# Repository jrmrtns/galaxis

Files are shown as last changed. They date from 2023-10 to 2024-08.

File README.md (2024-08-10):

# Galaxis

A tribute to Galaxis, an electronic game from Ravensburger, I loved to play as child.
<br/>This version of the game runs on a ESP32-C3 or ESP32-S3 and makes use of Bluetooth LE to connect up to four players.

The game is a kind of deductive boardgame like Mastermind for one to two players. The goal of the game is to discover
missing space ships, lost in space. These ships can be found if you enter coordinates into the board computer. Then the
computer answers with the number of ships which can be seen in horizontally, vertically or diagonal in a direct
line.<br/>
Who will find the missing spaceships first?

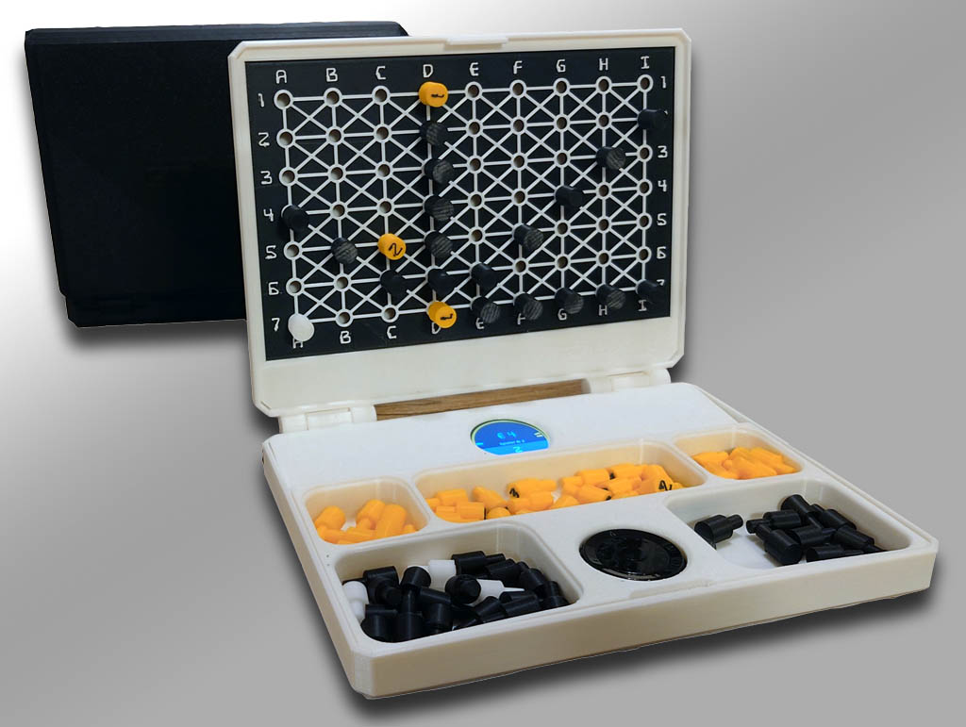
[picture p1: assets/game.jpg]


## Rules

Alarm at headquarters. Four spaceships are missing. By sending out radio signals in the different
directions, how many of the spaceships are seen from a certain point is reported back.

* Player A starts a new game by turning the dial until "New" appears on the display and confirming by pressing the
  middle button to confirm
* Up to three additional players can join a game by pressing "Join".
* A yellow ring on the screen indicates the active player
* The player sets a coordinate and presses the middle button.
* The search begins, a radio beam is emitted. Either a number appears on the screen, or a star if one of the ships has
  been found.
    * The number indicates how many of the spaceships can be seen in a horizontal, vertical or diagonal direction. The
      player plugs one of the yellow number pins into the coordinate on the coordinate system.
    * However, it should be noted that spaceships can lie in the radio shadow. This means that spaceships that
      in a direct line behind another spaceship are obscured by the first one and therefore cannot be seen.
      be seen.
      Example: Assume there are two spaceships at points C1 and C4. Then the radio beam from coordinate
      C7 only sees one spaceship (C4). The spaceship C1 is obscured. From position C3, however, two spaceships can be
      seen.
    * The black pins can be used to turn off coordinates where no more spaceships can be anymore.
    * If a spaceship has been found, this is indicated by '*' and the player has another turn
    * If there is a number, it is the next player's turn
    * While the game goes further, the players draw their conclusions from the coordinates entered and continue searching at the intersections.
* The first player to find all four spaceships wins the game.
* Press the middle button to start a new game.

Translated with www.DeepL.com/Translator (free version)

[The original rules from 1980 (in german language)](https://www.ravensburger.de/spielanleitungen/ecm/Spielanleitungen/Galaxis_Electronic.pdf)

## Deployment
If you prefer to use a precompiled version, just connect a suitable device to the USB port on your computer and visit [https://jrmrtns.github.io/galaxis/](https://jrmrtns.github.io/galaxis/)
in Chrome or Edge browser and follow instructions on the page.

## Build

The build-process requires an installation
of [PlatformIO Core CLI](https://docs.platformio.org/en/stable/core/index.html#piocore), or your favorite IDE with a
PlatformIO extension.

In case of PlatformIO Core CLI, please follow these instructions:

* `git clone https://github.com/jrmrtns/galaxis.git`
* `cd ./galaxis/Galaxis`
* Connect a Seeed XIAO ESP323 with a USB-C cable to your computer
* `pio run -e seeed_xiao_esp32c3 --target upload`

## Schematic

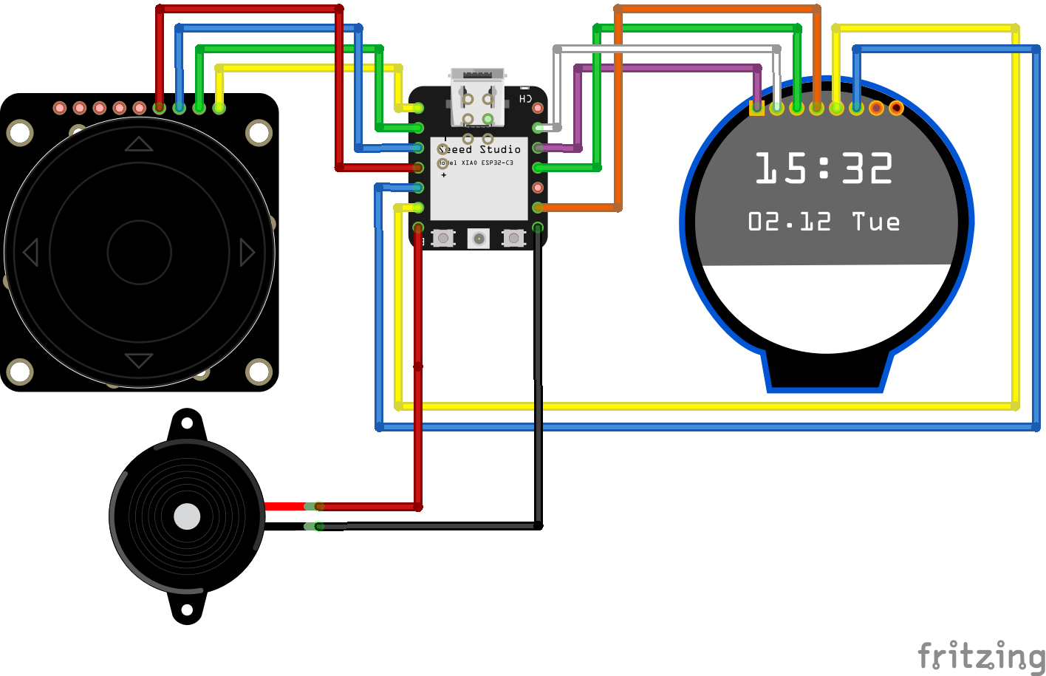
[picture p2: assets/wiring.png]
wiring diagram


## BOM

* [Display Waveshare 1.28 Round](https://www.berrybase.de/en/1.28-240x240-rundes-lcd-display-modul-65k-rgb-spi-interface?c=2384
  )

* [Seeed XIAO ESP32-C3](https://www.berrybase.de/en/seeed-xiao-esp32c3-winziges-mcu-board-mit-wlan-und-ble
  ) or [Seeed XIAO ESP32-S3](https://www.seeedstudio.com/XIAO-ESP32S3-p-5627.html)

* [Adafruit ANO Rotary Encoder](https://www.berrybase.de/en/adafruit-ano-scrollrad-drehgeber)

* [PCB for Adafruit ANO Rotary Encoder](https://www.berrybase.de/en/adafruit-breakout-pcb-fuer-ano-scrollrad-drehgeber)

* [Speaker (optional)](https://www.amazon.de/dp/B00X77TY96)

## 3D Files

Even if there is a single player version, I recommend to print the deck minimum twice. The hardware can connect up to four decks. 
To assemble one deck, you need to print all the following parts:

* 1 x [Bottom of the case](./3d/Boden.stl)
* 1 x [Lid of the case](./3d/Deckel.stl)
* 1 x [Inlay for the case](./3d/Inlay.stl)
* 1 x [Plate for the display](./3d/Display.stl)
* 1 x [Plate for the pins](./3d/Platte.stl)
* 50 x [Black Pins](./3d/BlackPin.stl)
* 5 x [Pin 0](./3d/Pin-0.stl)
* 10 x [Pin 1](./3d/Pin-1.stl)
* 10 x [Pin 2](./3d/Pin-2.stl)
* 10 x [Pin 3](./3d/Pin-3.stl)
* 5 x [Pin 4](./3d/Pin-4.stl)
* 4 x Pins with Spaceships (coming soon, in the meanwhile I use the black pins printed with white filament)

## Assembly

### Step 1

Prepare some cables. This is optional, you can soltder cables directly to the board. If you have a possibility to crimp
some conectors to cables, its getting easier to assemble. Otherwise you can
use [Dupont Cables](https://www.berrybase.de/40pin-jumper/dupont-kabel-male-female-trennbar?number=DUPK-40-FM-20) and remove one end.
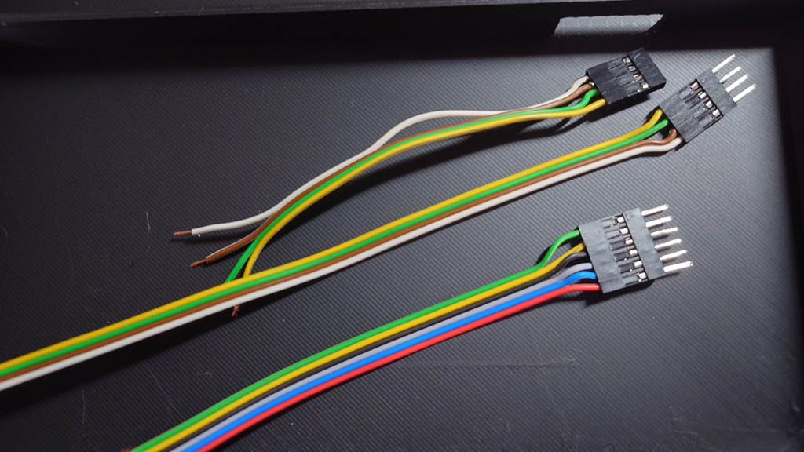
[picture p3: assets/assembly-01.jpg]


### Step 2

Solder the cable in the middle (from step 1 above) to the rotatry encoder
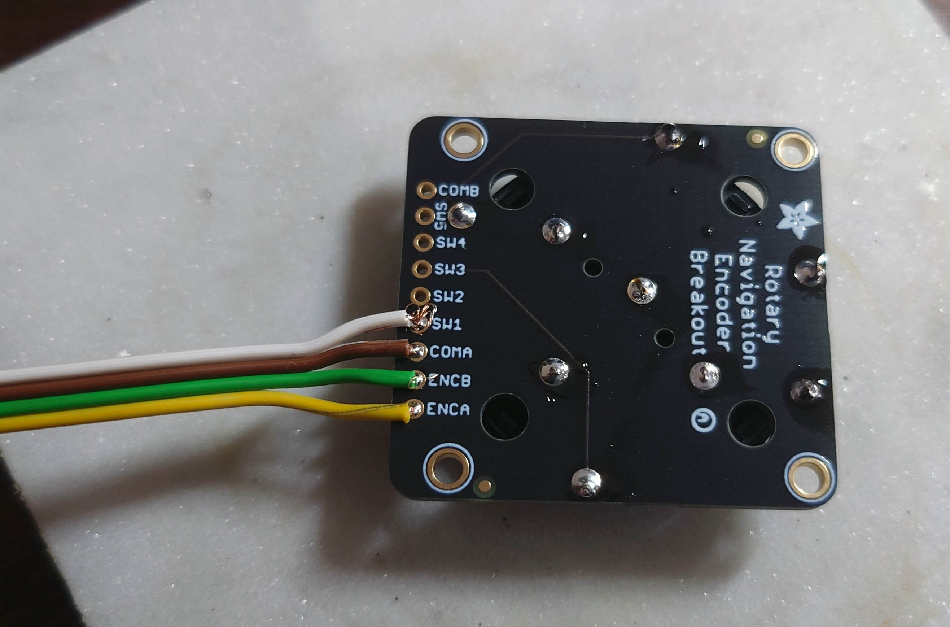
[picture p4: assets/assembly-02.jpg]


### Step 3

Place the cable between the gap of the bottom side of Inlay.stl.
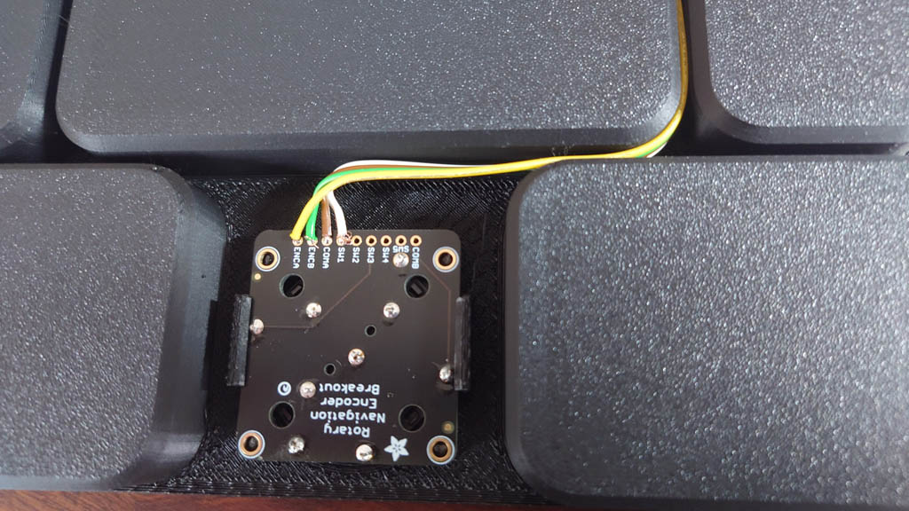
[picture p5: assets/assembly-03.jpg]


### Step 4

Insert the inlay into the bottom of the case.
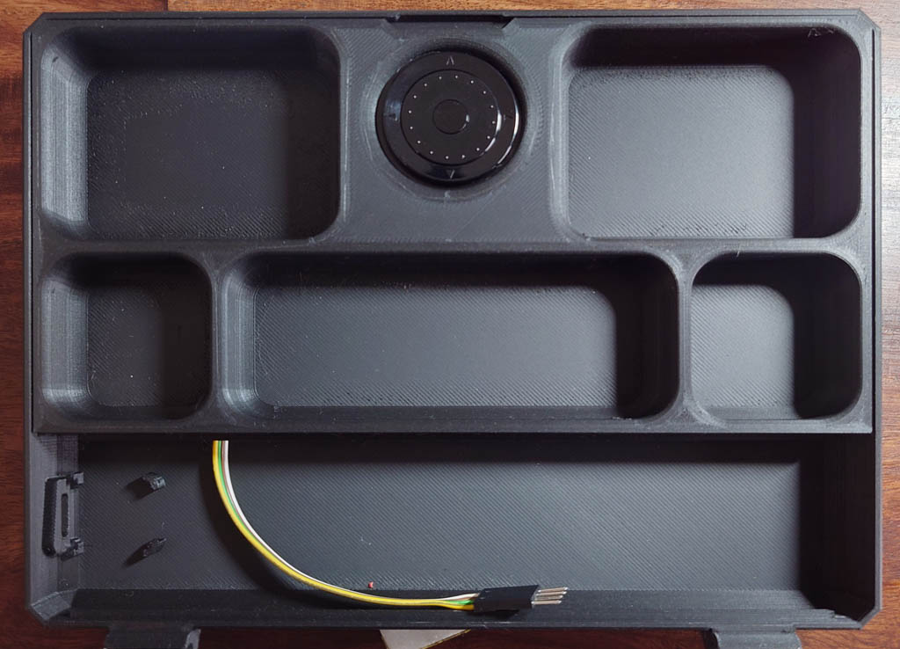
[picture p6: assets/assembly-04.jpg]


### Step 5

Solder the remaining two cables directly to the pads of the board.
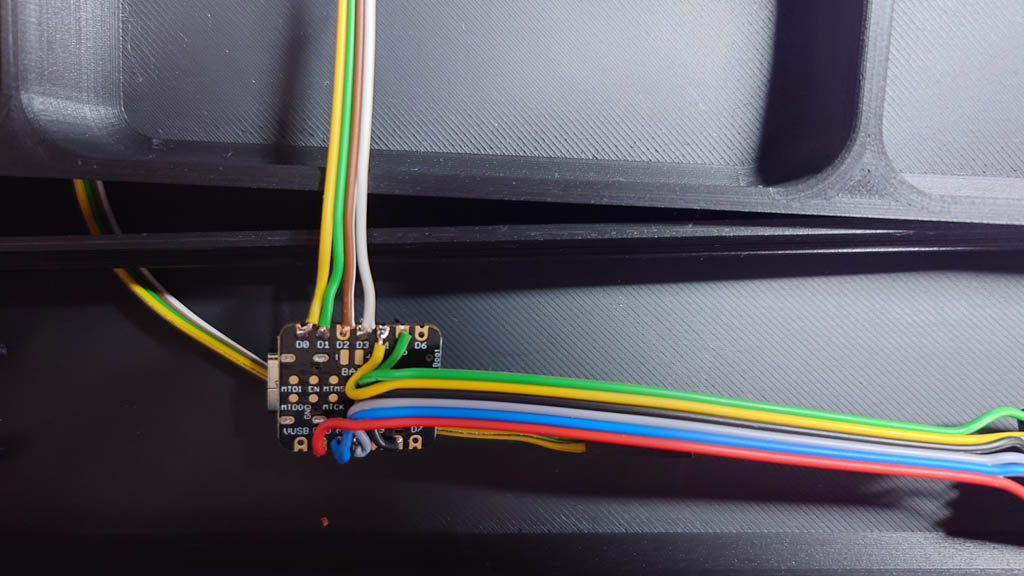
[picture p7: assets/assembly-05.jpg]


### Step 6

Let the board snap into the case.
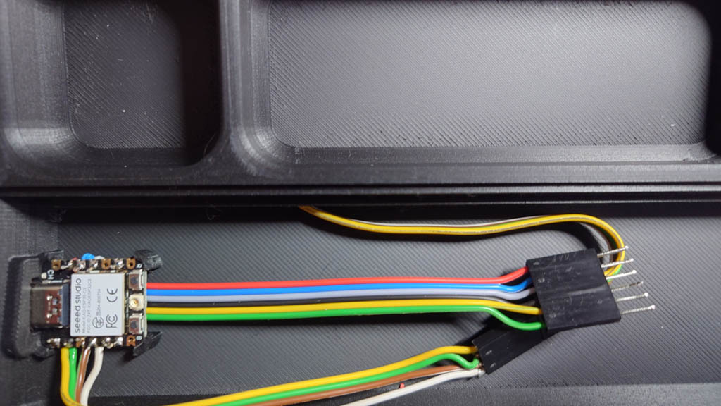
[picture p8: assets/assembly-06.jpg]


### Step 7

Connect the display and snap the display into Display.stl
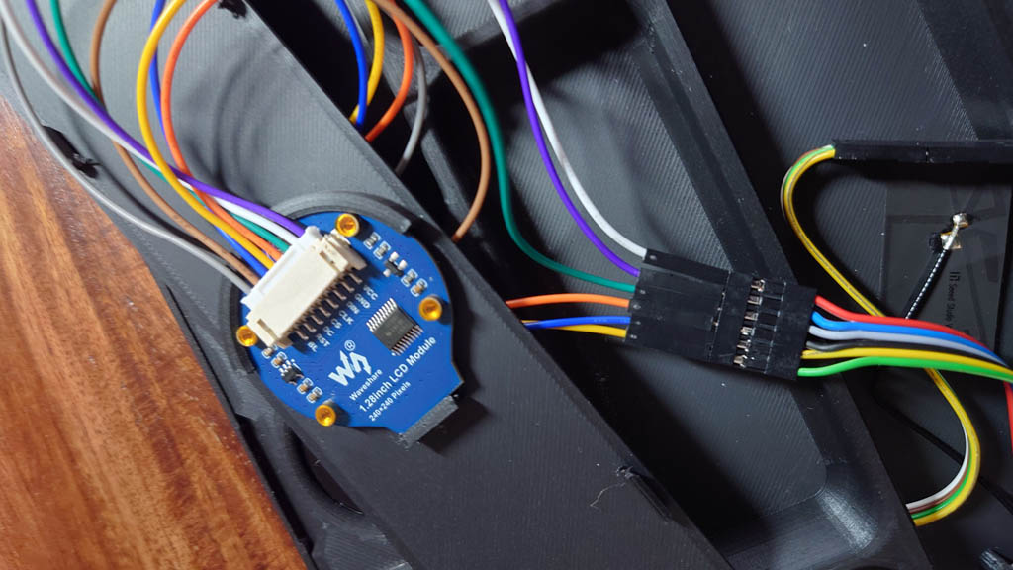
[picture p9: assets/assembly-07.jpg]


### Step 8

Build and upload the software to the chip, snap the Display.stl into the case and connect power to USB-C
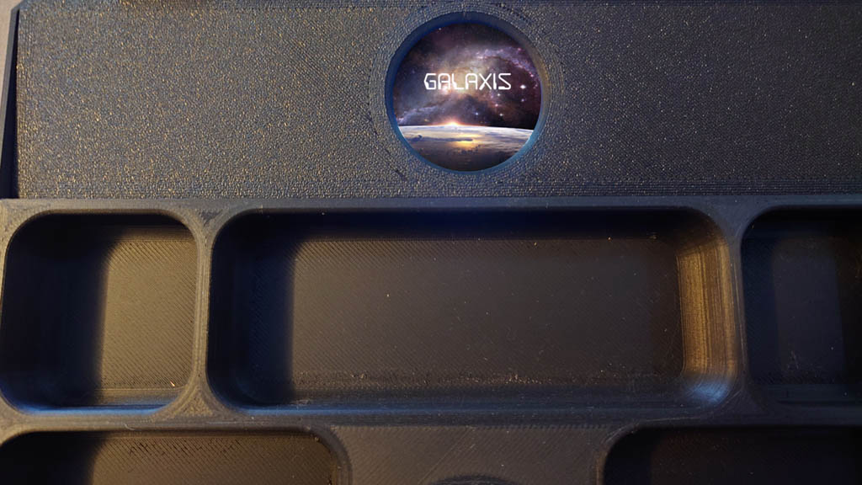
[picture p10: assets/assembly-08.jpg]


## Paperware

If you do not have access to a 3d printer, like to test the game before printing or while your printer is working (and mine was working for quite a long
time), there is a
[pdf to print out a board](./assets/sheet.pdf). This sheet replaces the 3d printed parts.

## Credits

* [Internet connection icons created by Erix - Flaticon](https://www.flaticon.com/free-icons/internet-connection)

* [Lumina Obscura](https://pixabay.com/users/luminas_art-4128746/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)

* [Font DestructoBeam BB Regular](https://fontsgeek.com/fonts/DestructoBeam-BB-Regular)

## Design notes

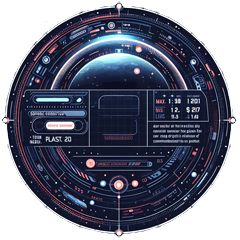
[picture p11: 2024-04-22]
Design/assets/_55fb20de-87ae-4109-bf2d-083075e9aa51.png

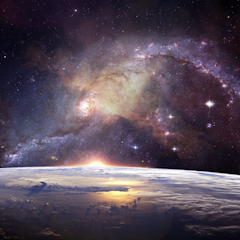
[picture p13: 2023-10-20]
Design/assets/bg.png

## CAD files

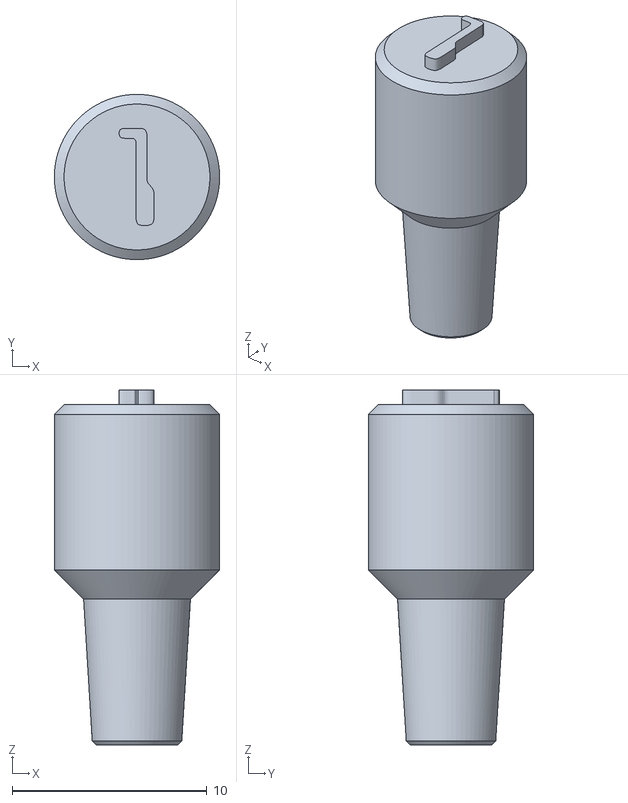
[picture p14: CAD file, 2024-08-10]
3d/Pin-1.stl
8.50 x 8.49 x 18.2

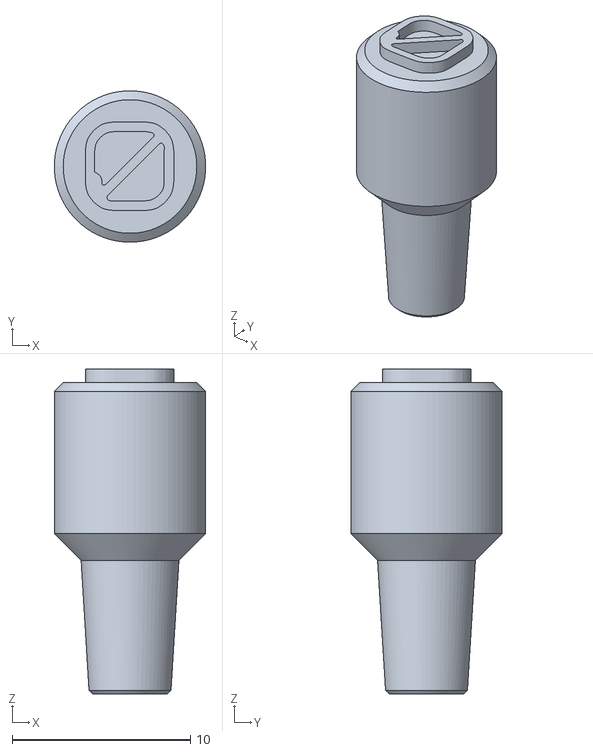
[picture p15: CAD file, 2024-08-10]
3d/Pin-0.stl
8.50 x 8.49 x 18.2

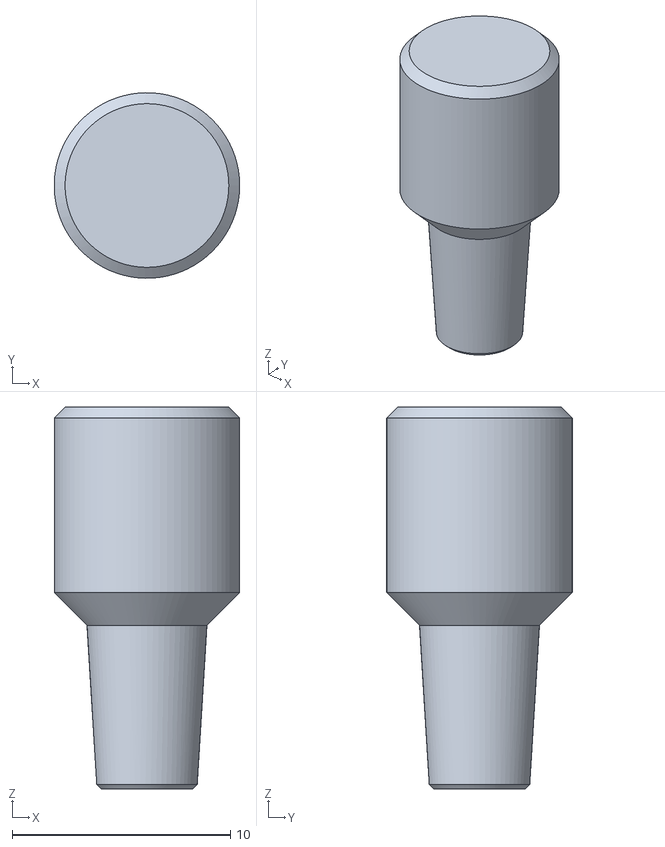
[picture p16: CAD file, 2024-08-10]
3d/BlackPin.stl
8.50 x 8.50 x 17.5

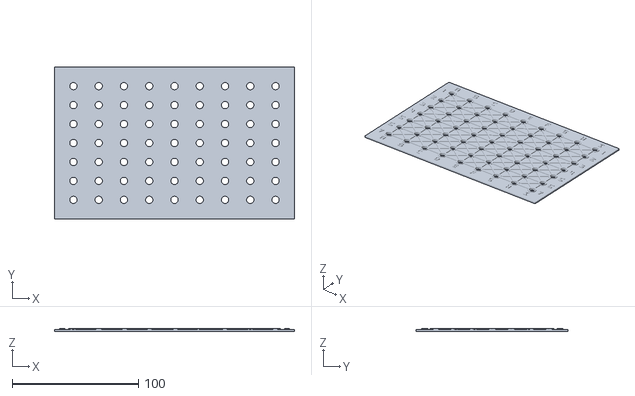
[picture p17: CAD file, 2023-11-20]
3d/Platte.stl
190.0 x 120.0 x 2.50

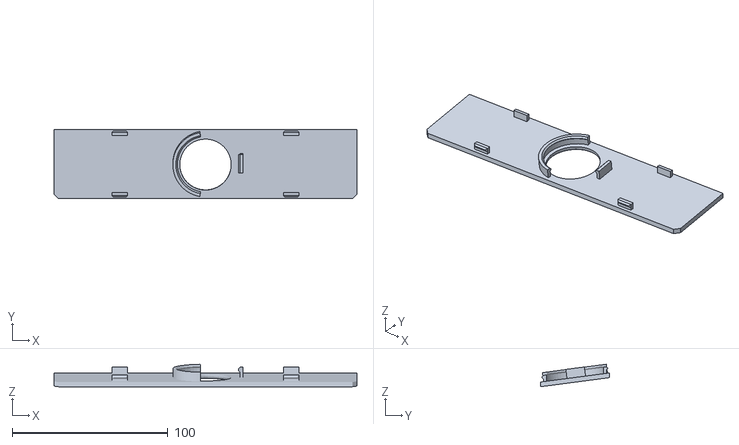
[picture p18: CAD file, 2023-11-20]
3d/Display.stl
194.5 x 44.6 x 14.5

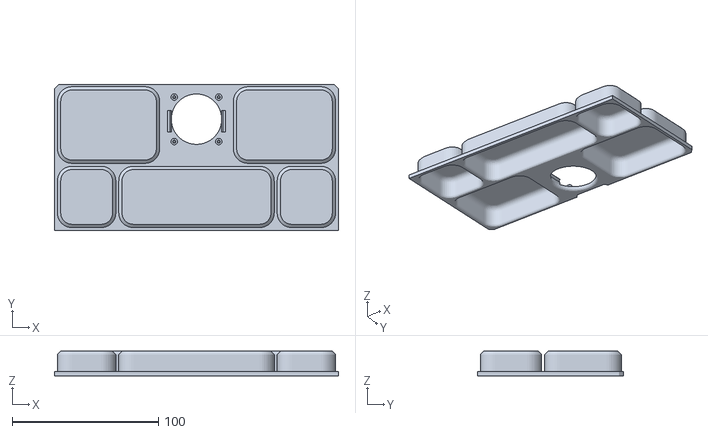
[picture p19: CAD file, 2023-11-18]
3d/Inlay.stl
194.5 x 100.0 x 17.0

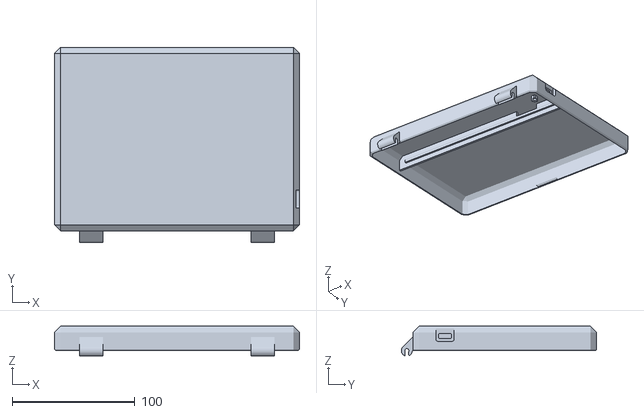
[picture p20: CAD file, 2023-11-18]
3d/Boden.stl
200.0 x 159.5 x 24.2

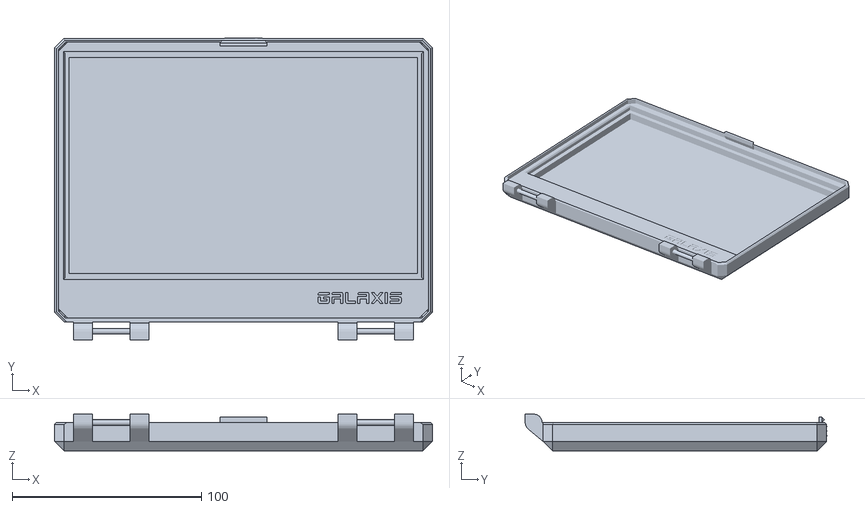
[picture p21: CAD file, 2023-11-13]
3d/Deckel.stl
200.0 x 159.6 x 19.5

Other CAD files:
3d/Pin-4.stl
3d/Pin-3.stl
3d/Pin-2.stl

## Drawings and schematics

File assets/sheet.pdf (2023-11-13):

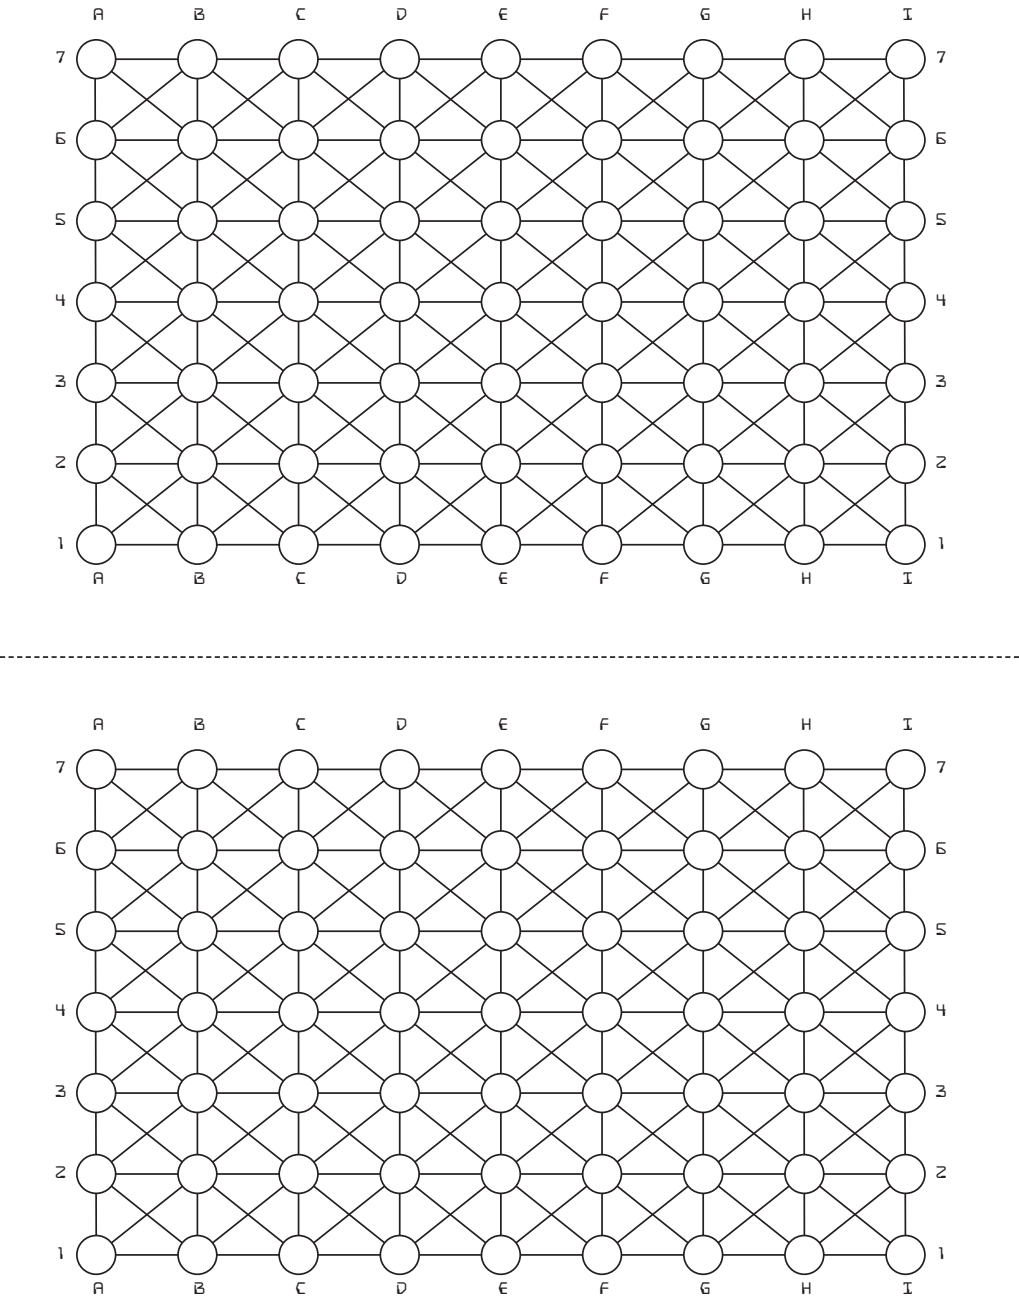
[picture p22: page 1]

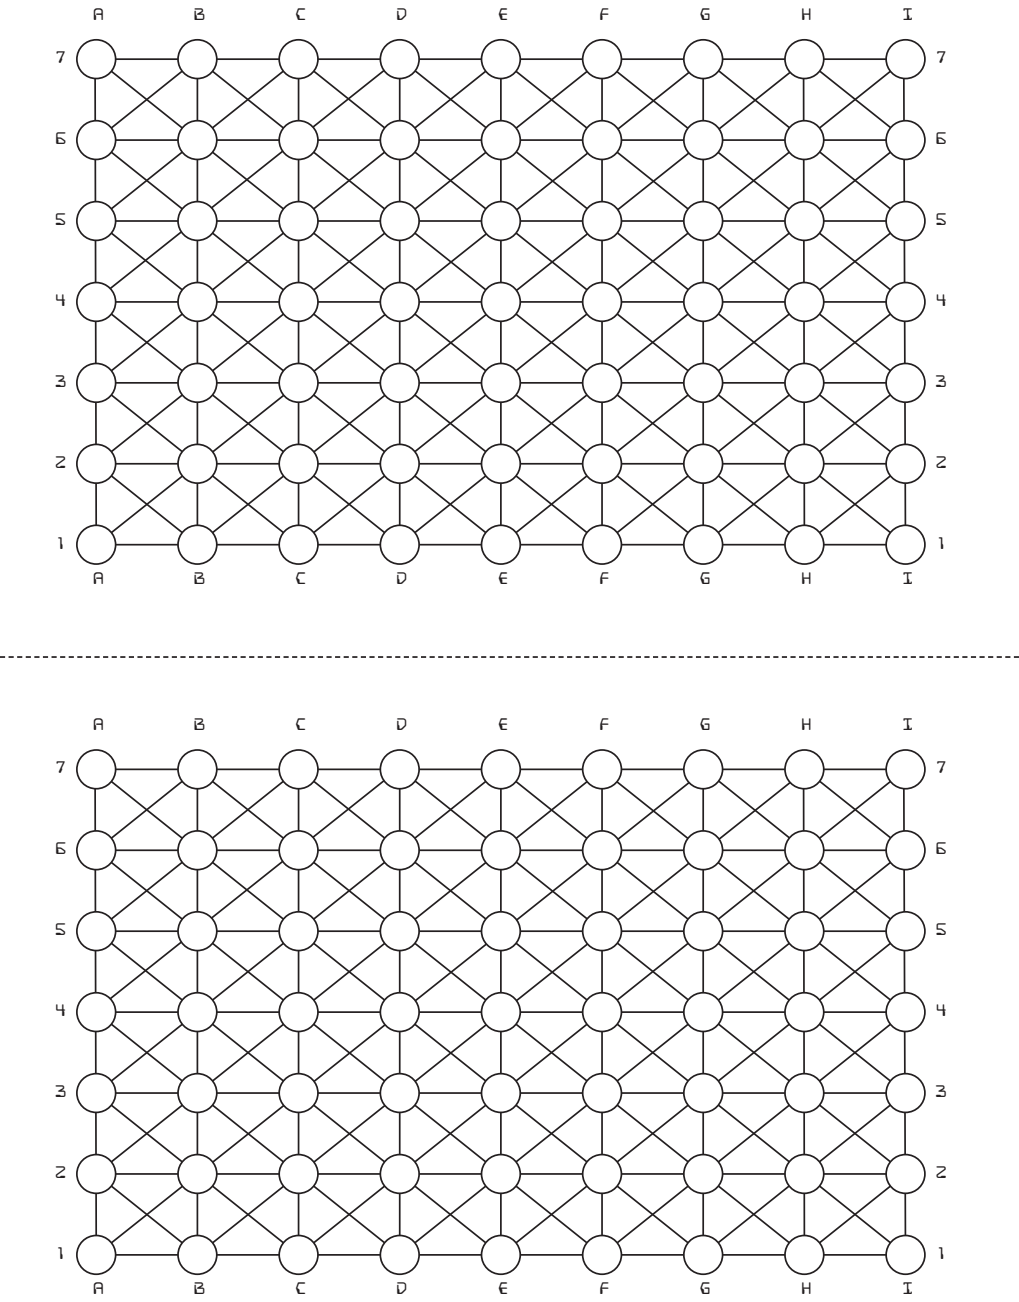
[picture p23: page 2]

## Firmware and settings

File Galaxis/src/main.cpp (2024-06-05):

#include <lvgl.h>
#include <TFT_eSPI.h>
#include <ui.h>
#include "RotaryEncoder.h"
#include <ArduinoBLE.h>
#include "screen_manager.h"
#include "settings.h"
#include "noise_maker.h"
#include "Preferences.h"

Preferences preferences;
RotaryEncoder *encoder = nullptr;
ScreenManager *screenManager = nullptr;
NoiseMaker *noiseMaker = nullptr;

int screen_rotation = 1;
bool playSound = true;
bool playIdleSound = true;

lv_obj_t *meters[MAX_PLAYERS];
lv_meter_indicator_t *indicators[MAX_PLAYERS];

lv_color_t primary = lv_palette_main(LV_PALETTE_RED);
lv_color_t secondary = lv_palette_main(LV_PALETTE_ORANGE);

static const uint16_t screenWidth = 240;
static const uint16_t screenHeight = 240;

static lv_disp_draw_buf_t draw_buf;
static lv_color_t buf[screenWidth * screenHeight / 10];

int lastButtonState = HIGH;
uint32_t lastButtonPress = 0;
uint32_t debounceTimeSpan = 25;

TFT_eSPI tft = TFT_eSPI(screenWidth, screenHeight);

#if LV_USE_LOG != 0
/* Serial debugging */
void my_print(const char * buf)
{
    //Serial.printf(buf);
    Serial.flush();
}
#endif

void checkPosition() {
    encoder->tick();
}

void sleep(bool value) {
    if (value) {
        tft.writecommand(0x10);   // Send command to put the display to sleep.
        delay(150);               // Delay for shutdown time before another command can be sent.
    } else {
        tft.init();               // This sends the wake up command and initialises the display
        delay(50);                // Extra delay to stop a "white flash" while the TFT is initialising.
    }
}

int getAngle(uint8_t i) {
    switch (i) {
        case 0: return 180;
        case 1: return 330;
        case 2: return 255;
        case 3: return 60;
    }
    return 0;
}

lv_color_t getColor(uint8_t i){
    switch (i) {
        case 0: return primary;
        case 1: return secondary;
        case 2: return lv_palette_main(LV_PALETTE_CYAN);
        case 3: return lv_color_hex(0xffffff);
    }
    return lv_palette_main(LV_PALETTE_NONE);
}

void extendGameView() {
    lv_obj_set_style_text_align(ui_StatusLabel, LV_TEXT_ALIGN_CENTER, LV_PART_MAIN | LV_STATE_DEFAULT);

    lv_obj_set_style_text_color(ui_Coordinates, primary, LV_STATE_DEFAULT);
    lv_obj_set_style_text_color(ui_SearchResult, primary, LV_STATE_DEFAULT);
    lv_obj_set_style_text_color(ui_MainMenuItem, primary, LV_STATE_DEFAULT);
    lv_obj_set_style_text_color(ui_GameOverItem, primary, LV_STATE_DEFAULT);
    lv_obj_set_style_bg_color(ui_Game, secondary, LV_STATE_CHECKED);

    for (int i = 0; i < MAX_PLAYERS; ++i) {
        auto meter = lv_meter_create(ui_Game);
        lv_obj_remove_style(meter, nullptr, LV_PART_INDICATOR);
        lv_obj_remove_style(meter, nullptr, LV_PART_MAIN);

        lv_obj_center(meter);
        lv_obj_set_size(meter, 220, 220);

        lv_meter_scale_t *scale = lv_meter_add_scale(meter);
        lv_meter_set_scale_ticks(meter, scale, 5, 6, 20, lv_color_hex(0x292831));
        lv_meter_set_scale_range(meter, scale, 0, 100, 30, getAngle(i));

        auto indicator = lv_meter_add_arc(meter, scale, 20, getColor(i), 0);
        meters[i] = meter;
        indicators[i] = indicator;
    }
}

void initialize_encoder() {
    pinMode(PIN_ENC_BUTTON, INPUT_PULLUP);

    encoder = new RotaryEncoder(PIN_ENC_IN1, PIN_ENC_IN2, RotaryEncoder::LatchMode::TWO03);
    encoder->setPosition((1000 * MAX_X * MAX_Y));

    attachInterrupt(digitalPinToInterrupt(PIN_ENC_IN1), checkPosition, CHANGE);
    attachInterrupt(digitalPinToInterrupt(PIN_ENC_IN2), checkPosition, CHANGE);
}

void dispFlushCallback(lv_disp_drv_t *disp, const lv_area_t *area, lv_color_t *color_p) {
    int32_t w = (area->x2 - area->x1 + 1);
    int32_t h = (area->y2 - area->y1 + 1);

    tft.startWrite();
    tft.setAddrWindow(area->x1, area->y1, w, h);
    tft.pushColors((uint16_t *) &color_p->full, w * h, true);
    tft.endWrite();

    lv_disp_flush_ready(disp);
}

void setup() {
    Serial.begin(115200);
    preferences.begin("galaxis", true);
    playSound = preferences.getBool("Sound", true);
    playIdleSound = preferences.getBool("IdleSound", true);
    preferences.end();

    ledcSetup(TONE_PWM_CHANNEL, 12000, 9);
    ledcAttachPin(PIN_TONE_OUTPUT, TONE_PWM_CHANNEL);
    noTone(PIN_TONE_OUTPUT);

#ifdef PIN_ENC_GROUND
    pinMode(PIN_ENC_GROUND, OUTPUT);
    digitalWrite(PIN_ENC_GROUND, LOW);
#endif

#ifdef PIN_SPEAKER_GROUND
    pinMode(PIN_SPEAKER_GROUND, OUTPUT);
    digitalWrite(PIN_SPEAKER_GROUND, LOW);
#endif

    lv_init();

    initialize_encoder();
    screenManager = new ScreenManager(encoder);
    noiseMaker = new NoiseMaker();

    if (!BLE.begin()) {
        Serial.println("starting Bluetooth® Low Energy module failed!");

        while (true);
    }

#if LV_USE_LOG != 0
    lv_log_register_print_cb( my_print );
#endif

    tft.begin();
    tft.setRotation(screen_rotation);

    lv_disp_draw_buf_init(&draw_buf, buf, nullptr, screenWidth * screenHeight / 10);

    static lv_disp_drv_t disp_drv;
    lv_disp_drv_init(&disp_drv);

    disp_drv.hor_res = screenWidth;
    disp_drv.ver_res = screenHeight;
    disp_drv.flush_cb = dispFlushCallback;
    disp_drv.draw_buf = &draw_buf;
    lv_disp_drv_register(&disp_drv);

    ui_init();
    extendGameView();

    lv_timer_handler();
    delay(2500);

    screenManager->show(MENU);
}

void checkButtonState() {
    int button = digitalRead(PIN_ENC_BUTTON);
    if (button != lastButtonState && ((millis() - lastButtonPress) > debounceTimeSpan)) {
        lastButtonState = button;
        lastButtonPress = millis();
    }

    if (button == LOW && lastButtonState == LOW && ((millis() - lastButtonPress) > 3 * 1000)) {
        esp_restart();
    }
}

void loop() {
    checkButtonState();
    lv_timer_handler();
    BLE.poll();
    noiseMaker->loop();
    screenManager->loop();
}

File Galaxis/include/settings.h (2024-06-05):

//
// Created by jmartens on 19.10.2023.
//

#ifndef GALAXIS_SETTINGS_H
#define GALAXIS_SETTINGS_H

#ifdef ARDUINO_M5Stack_StampS3
#define PIN_ENC_IN1 41
#define PIN_ENC_IN2 40
#define PIN_ENC_BUTTON 42
#define PIN_TONE_OUTPUT 3
#define TONE_PWM_CHANNEL 0
#else
#define PIN_ENC_IN1 D1
#define PIN_ENC_IN2 D0
#define PIN_ENC_GROUND D2
#define PIN_ENC_BUTTON D3
#define PIN_TONE_OUTPUT D6
#define PIN_SPEAKER_GROUND D7
#define TONE_PWM_CHANNEL 0
#endif

#define MAX_X 9
#define MAX_Y 7
#define SHIP_COUNT 4
#define MAX_PLAYERS 4
#define IDLE_TIME 15

#define GALAXIS_SERVICE_UUID "5A9AB000-CF0B-4281-BB4F-60C67E9ACC28"
#define GALAXIS_CHARACTERISTIC_UUID "5A9AB001-CF0B-4281-BB4F-60C67E9ACC28"

#ifdef DE
#define START_MESSAGE "Starte ...\noder warte auf weitere Spieler"
#define WAITING_FOR_PLAYER "Warte auf "
#define CONNECTING "Warte auf weitere Spieler...\noder spiele alleine"
#define WAIT_JOIN "Warte auf Verbindung..."
#define CONNECTED "Verbunden: "
#define PLAYER "Hallo "
#define GAME_OVER_MESSAGE "Game over"
#define GAME_OVER_HINT "Nochmal spielen?"
#define GAME_OVER_WINNER_MESSAGE "Gewinner"
#define GAME_OVER_WINNER_HINT "Nochmal spielen?"
#define MAIN_MENU_SINGLE "Einzel"
#define MAIN_MENU_SINGLE_HINT "Einzelspiel"
#define MAIN_MENU_SETTINGS "Einst."
#define MAIN_MENU_SETTINGS_HINT "Einstellungen"
#define MAIN_MENU_NEW_GAME "Neu"
#define MAIN_MENU_NEW_GAME_HINT "Neues Spiel starten"
#define MAIN_MENU_JOIN "Beitreten"
#define MAIN_MENU_JOIN_HINT "Einem Spiel beitreten"
#define MAIN_MENU_OFF "Off"
#define GAME_SCANNING_MESSAGE "Suche"
#else
#define START_MESSAGE "Start...\nor wait for other players"
#define WAITING_FOR_PLAYER "Waiting for "
#define CONNECTING "Wait for further players\nor just start single"
#define WAIT_JOIN "Waiting for connection..."
#define CONNECTED "Connected: "
#define PLAYER "Hi  "
#define GAME_OVER_MESSAGE "Game over"
#define GAME_OVER_HINT "Press button for new game"
#define GAME_OVER_WINNER_MESSAGE "** You did it **"
#define GAME_OVER_WINNER_HINT "Press button for new game"
#define MAIN_MENU_SINGLE "Single"
#define MAIN_MENU_SINGLE_HINT "Singleplayer game"
#define MAIN_MENU_NEW_GAME "New"
#define MAIN_MENU_NEW_GAME_HINT "Start new game"
#define MAIN_MENU_SETTINGS "Settings"
#define MAIN_MENU_SETTINGS_HINT "Settings"
#define MAIN_MENU_JOIN "Join"
#define MAIN_MENU_JOIN_HINT "Join a game"
#define MAIN_MENU_OFF "Off"
#define GAME_SCANNING_MESSAGE "Scanning"
#endif

const float conversion_factor = 3.3f / (1 << 12) * 3;
static const char *playerNames[] = {
        "Luke Skyrunner",
        "Han Solar",
        "James T. Smirk",
        "Tricia McMillan"
};

#endif //GALAXIS_SETTINGS_H

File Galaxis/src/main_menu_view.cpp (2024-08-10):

//
// Created by jmartens on 04.11.2023.
//

#include "main_menu_view.h"

#include <utility>
#include "core/lv_disp.h"
#include "ui.h"
#include "settings.h"
#include "view-update-message.h"

MainMenuView::MainMenuView(RotaryEncoder *encoder, std::shared_ptr<MainMenuController> controller,
                           std::shared_ptr<MainMenuModel> model) : _encoder(encoder),
                                                                   _controller(std::move(controller)),
                                                                   _model(std::move(model)) {
    _model->registerObserver(this);
}

void MainMenuView::show() {
    updateMenuItem();

    lv_scr_load_anim(ui_MainMenu, LV_SCR_LOAD_ANIM_FADE_ON, 500, 0, false);
}

Screen MainMenuView::loop() {
    int position = _encoder->getPosition();
    if (_lastPosition != position) {
        _controller->move(position);
        _lastPosition = position;
    }

    int button = digitalRead(PIN_ENC_BUTTON);
    if (button != _lastButtonState && ((millis() - _lastButtonPress) > _debounceTimeSpan)) {
        if (button == HIGH) {
            _controller->btnClick(position);
        }
        _lastButtonState = button;
        _lastButtonPress = millis();
    }

    return _model->getSelectedMenuItem();
}

void MainMenuView::update(ViewUpdateMessage param) {
    switch ((ViewUpdateMessage) param) {
        case Coordinates:
        case SearchResult:
        case ShipCount:
        case Active:
        case Hint:
        case Connected:
        case GameOver:
        case Started:
        case Searching:
        case Round:
            break;
        case MenuItemChanged:
            updateMenuItem();
            break;
    }
}

void MainMenuView::updateMenuItem() {
    String txt = "";
    String hint = "";

    if (_model->getMenu() == 0) {
        txt = MAIN_MENU_JOIN;
        hint = MAIN_MENU_JOIN_HINT;
    }
    if (_model->getMenu() == 1) {
        txt = MAIN_MENU_NEW_GAME;
        hint = MAIN_MENU_NEW_GAME_HINT;
    }
    if (_model->getMenu() == 2) {
        hint = MAIN_MENU_SETTINGS_HINT;
        txt = MAIN_MENU_SETTINGS;
    }
    if (_model->getMenu() == 3)
        txt = MAIN_MENU_OFF;

    lv_label_set_text(ui_MainMenuItem, txt.c_str());
    lv_label_set_text(ui_MainMenuHint, hint.c_str());
}

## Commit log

2023-10-23 Add currentUserId to guess
2023-10-28 Before switchng device and central logic
2023-10-29 Switching device and central logic
2023-11-03 3d files added
    [BlackPin.stl, Boden.stl, Deckel.stl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]
2023-11-08 Reduce lvgl footprint
2023-11-10 Indicator added
    [Inlay.stl]
2023-11-12 First prototype
2023-11-24 Make use of unique_ptr for board
2023-11-24 Smaller improvements (#9)
    * Add an additional, local configuration for platformio.ini
    * Make use of unique_ptr for board
    * Make use of unique_ptr for board
    ---------
2024-04-19 Dev (#11)
    * Make use of to smart pointers
    * Add AI generated background image
    * random seed
    * Use build flag for random seed
    * workflow added
    * Second try
    * Moved action folder to root
    * Trying pio ci
    * Using pio run
    * Missing argument fixed
    * Keep artifact
    * Build multiple firmwares
    * Build EN version
    * Build EN version
    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
    [ble_central_game.cpp, galaxis_game_view.cpp, main.cpp]
2024-04-20 Dev (#13)
    * Removed duplicate entry
    * Wildcard upload
    * In one artifact
    * Try copy files
    * All files in one artifact
    * node build
    * Set directory
    * Build web app
    * dir
    * npm
    *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
2024-04-20 Dev (#15)
    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
2024-04-20 Dev (#17)
    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
2024-04-21 Dev (#18)
    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
2024-04-22 Merge pull request #19
    * Merge remote-tracking branch 'origin/dev' into dev
    * Merge remote-tracking branch 'origin/dev' into dev
    * All files in one artifac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
2024-05-03 Merge pull request #26
    * Search animation added
    * Merge branch 'refs/heads/tone' into dev
    * Search animation added
    * Search animation translated
    * Merge branch 'refs/heads/tone' into dev
    * Build fixed
    * Merge branch 'refs/heads/tone' into dev
    [settings.h]
2024-05-03 dev (#27)
    * Tone deactivated
    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
    [main.cpp]
2024-05-04 Merge pull request #28
    * Merge branch 'main' into dev
    * Merge branch 'refs/heads/main' into dev
    * Shorten search time
    * Shorten search time
    * Merge remote-tracking branch 'origin/tone' into tone
    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
    [galaxis_game_view.cpp, main.cpp, main_menu_view.cpp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]
2024-05-12 Speaker added to wiring
2024-05-14 Hints and flow optimized
2024-06-11 Pins changed for easier insertation
    [BlackPin.stl, Pin-0.stl, Pin-1.stl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]
